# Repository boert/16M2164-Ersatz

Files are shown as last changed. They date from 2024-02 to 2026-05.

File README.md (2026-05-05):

# Ersatz für Hybridschaltkreis 16M2164

Der 16M2164 von KWH (Keramische Werke Hermsdorf) ist ein Speicherschaltkreis in Hybridbauweise.
Er ist vermutlich nur in sehr geringen Stückzahlen hergestellt worden.
Der Hybridschaltkreis enthält 16 mal das Die (ein Stück vom Halbleiterwafer) des Schaltkreises U2164 sowie einige Stützkondensatoren auf einem Keramiksubstrat.  
Der U2164 ist ein dynamischer RAM mit 64kBit.
In Summe enthält der 16M2164 ein MegaBit bzw. 128 kByte Speicher.

Zum Einsatz kommt der Schaltkreis 16M2164 im Speichermodul M036 für den KC85 aus Mühlhausen [^1].  
Um die unbestückten Leiterplatte, die für dieses Modul im Umlauf sind, nutzen zu können, benötigt man i.d.R. einen Ersatz für den 16M2164.

Von U. Zander stammt die urspüngliche Idee einer Schaltkreisersatzplatine, die nur mit vier dRAM-Schaltkreisen auskommt [^2].
Diese Lösung funktioniert leider nicht perfekt.

> [!Note]
> ### dynamischer Speicher
> Bei dynamischen Speichern wird die Information als Ladung in Kondensatoren abgebildet. Durch Leckströme verliert sich diese Ladung mit der Zeit und muß daher regelmäßig aufgefrischt werden (Refresh). Dies geschiet u.a. beim Aktivieren des /RAS-Signals. Der Hersteller gibt dabei an, in welchem Zeitraum jede ROW-Adresse einmal aktiviert werden muß. Normalerweise wird die angelegte ROW-Adresse vom Speichercontroller entsprechend hochgezählt. Bei einem geschickt adressierten Bildwiederholspeicher könnte man auf den Refresh verzichten, da dort durch regelmäßige Lesezugriffe die Information beim Lesen aufgefrischt wird.

In der folgenden Tabelle sind die Refreshzyklen eingier dRAM-Hersteller aufgeführt:

Hersteller  | Speicher-IC | Speichergröße | Refreshzyklen | Refreshzeit | Gehäuse
----------  | ----------- | ------------: | ------------: | ----------: | -------
&nbsp;      | &nbsp;      | _x1 Bit dRAMs_ 
Mostek      | MK4096      |   4k x 1      |   64          |  2 ms       | DIP16
Mostek      | MK4116      |  16k x 1      |  128          |  2 ms       | DIP16
NEC         | µPD4164     |  64k x 1      |  128          |  2 ms       | DIP16
Mostek      | MK4564      |  64k x 1      |  128          |  2 ms       | DIP16, PLCC18
Mostek      | MK4164      |  64k x 1      |  128          |  2 ms       | DIP16
National    | NMC4164     |  64k x 1      |  256          |  4 ms       | DIP16
Siemens     | HYB4164     |  64k x 1      |  256          |  4 ms       | DIP16
Mostek      | MK41256     | 256k x 1      |  256          |  4 ms       | DIP16, PLCC18
Siemens     | HYB51100    |   1M x 1      |  512          |  8 ms       | SOJ26
&nbsp;      | &nbsp;      | _x4 Bit dRAMs_ 
TI          | TMS4416     |  16k x 4      |  256          |  4 ms       | DIP18, PLCC18
TI          | SMJ4464     |  64k x 4      |  256          |  4 ms       | DIP18, PLCC18
NEC         | µPD41464    |  64k x 4      |  256          |  4 ms       | DIP18, PLCC18
TI          | SMJ4464     |  64k x 4      |  256          |  4 ms       | DIP18, PLCC18
Mitsubishi  | M5M4464A    |  64k x 4      |  256          |  4 ms       | DIP18, PLCC18, ZIP20
Samsung     | KM41464A    |  64k x 4      |  256          |  4 ms       | DIP18, PLCC18, ZIP20
Siemens     | HYB514256   | 256k x 4      |  512          |  8 ms       | DIP20, SOJ26/20
NEC         | µPD424400   |   1M x 4      | 1024          | 16 ms       | TSOP26, SOJ26/20

Eine Vergleichstabelle von 64k-Bit dRAM-Chips findet sich unter [^7].

Die verwendeten Speicher-IC der Größe 64k x 4 Bit benötigen alle 256 Refreshzyklen. Damit muß der Zähler für den Refresh mindestens acht Bit breit sein.
Die U880/Z80-CPU enthält nur einen 7 Bit-Refreshzähler, der für die Bausteine mit 64 oder 128 Refreshzyklen ausreichend ist.
Die obere Hälfte des Speichers erhält keinen definierten Refresh und verliert mit der Zeit ihren Inhalt.

Im Folgenden sind drei Wege aufgezeigt, um den fehlenden Speicher zu ersetzen: Variante R, Variante D und Variante S.

## Variante R: Refresh
Der übliche Weg ist es, den Refreshzähler zu erweitern.  
Ein Schaltung dafür findet sich z.B. in [^3].

Auch im Grundgerät D001 (KC85/4) werden aus den Signalen /rfsh, mreq und ab6 die Signale RF7 und RF8 gebildet, die den Refreshzähler des Z80 auf 9 Bit erweitern:

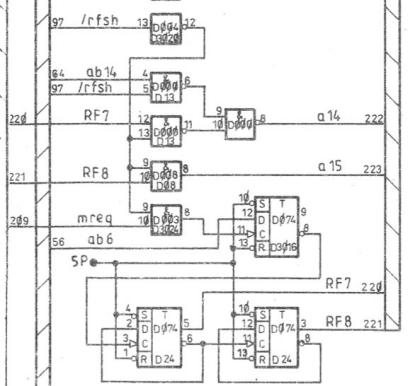
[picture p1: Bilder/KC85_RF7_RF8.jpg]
KC85/4, erweiterter Refresh
  

Der erweiterte Refreshzähler steht leider nur den interne RAM-Bausteinen auf der Hauptplatine zur Verfügung.

Am Modul 16M2164 steht weder der erweiterte Refreshzähler, noch das eigentliche Refresh-Signal zur Verfügung.  
Zumindest des Refresh-Signal müsste auf separatem Weg zugeführt werden.  
Daher wurde diese Lösung nicht weiter verfolgt.

## Variante D: dynamischer RAM
Im Robotrontechnik-Forum ist ein Bild vom Innenaufbau des 16M2164 verlinkt [^4]. Mit etwas Geschick lassen sich die 16 Stück U2164 auf einer Aufsteckplatine plazieren und so die Schaltung des 16M2164 1:1 nachbilden.
Die erste Hälfte der Schaltkreise sitzt direkt auf der Adapterplatine. Die zweite Hälfte wird huckepack auf die bereits eingelöteten Schaltkreise gelötet und bis auf das /CAS-Signal parallel geschaltet.
Die die untere Hälfte wird mit dem Signal /CAS0 aktiv. Die obere Hälfte wird entsprechend mit dem /CAS1-Signal aktiv.

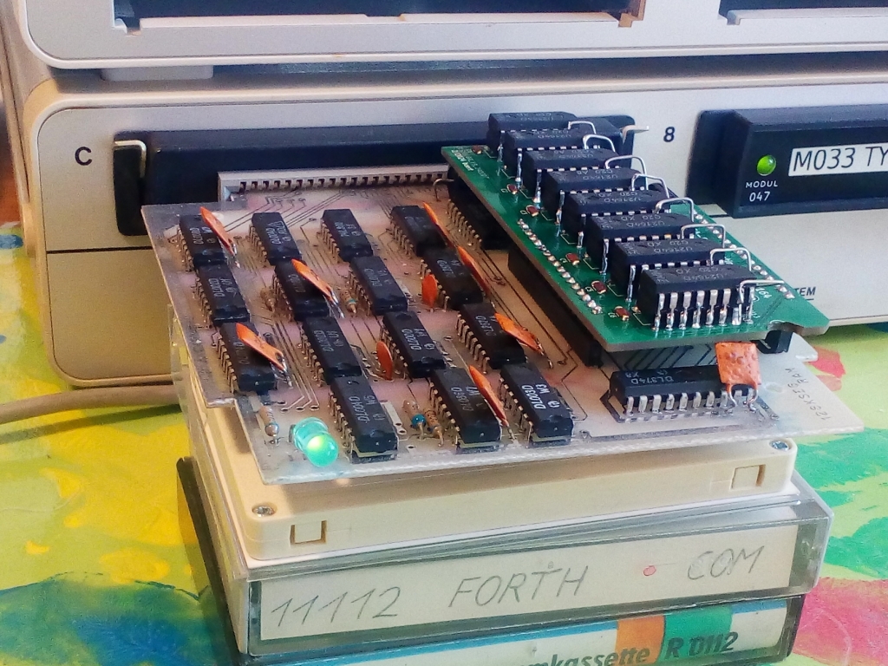
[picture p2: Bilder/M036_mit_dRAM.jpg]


Der große Nachteil dieser Lösung: sie benötigt zuviel Platz und passt nicht mehr in ein Modulgehäuse bzw. den Modulschacht.
Das M036 läßt sich so nur offen an einem Adapter M007 betreiben.

## Variante S: statischer RAM
Warum ersetzen wir nicht die dRAM-Schaltkreise durch einen einzelnen SRAM der Größe 128kx8 Bit?
Ein SRAM benötigt die Signale /CS, /WE und /OE sowie Daten und Adressen.
Am Bestückungsplatz für das 16M2164 stehen die Signale /RAS, /CAS0 (unter Hälfte), /CAS1 (obere Hälfte) und /WE zur Verfügung. Die Adressenleitungen sind multiplext.

Die Adressen müssen wieder demultiplext werden und für die Steuersignale ist eine Signalanpassung nötig.
Ein Latch, was mit dem invertierten /RAS-Signal angesteuert wird, speichert die eine Hälfte der Adressinformation. Die andere Hälfte der Adresse wird direkt an den SRAM durchgereicht. Aus /CAS0 und /CAS1 wird das /CS-Signal gebildet. Aus dem Signal /WE wird noch das Signal /OE abgeleitet.

Da es ein RAM ist, dürfen Datenleitungen problemlos miteinander vertauscht werden. Ebenso kann man Adressleitungen tauschen, solange keine Sonderfunktionen realisiert sind.
Damit wird das Routing auf der zweilagigen Platine erleichtert.

Im Bild ist die Lösung zu sehen, die von der Grundfläche dem Original 16M2164 entspricht.
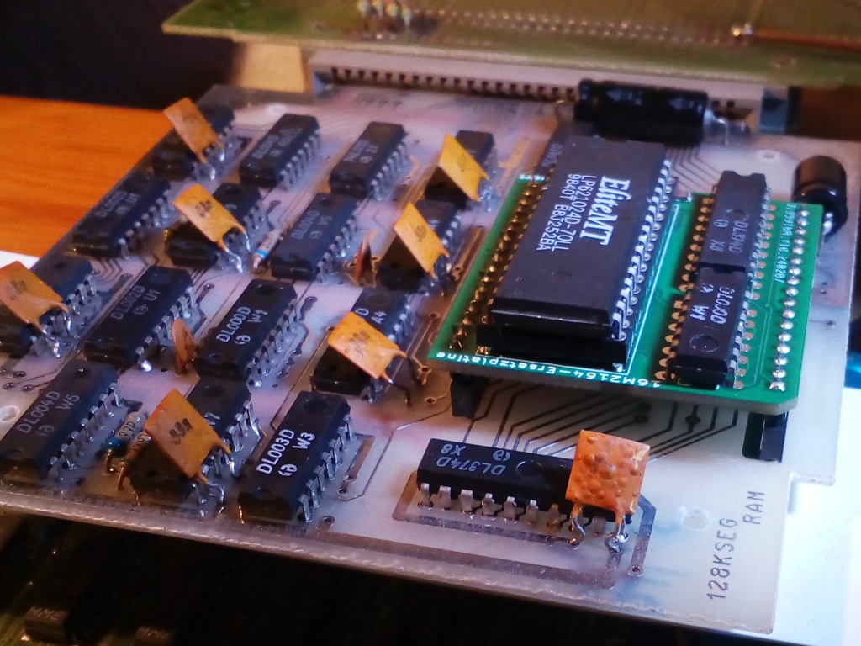
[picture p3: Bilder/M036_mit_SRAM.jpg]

Mit flachen Präzisions-Stiftleisten (und ohne IC-Sockel für den SRAM-Chip) läßt sich die Ersatzplatine im Modulgehäuse unterbringen.
Der IC-Sockel im Bild diente für den Test verschiedener SRAM-Schaltkreise.

# Test im M036 #
Für einen Speichertest im KC85/4 bzw. KC85/5 bietet sich das Programm RAMTEST3 an.
Um gezielt nur das Speichermodul M036 zu testen kann man mit `TESTM` den Modulschacht mit angeben, z.B. `TESTM 0C`.
Anschließend werden die acht Segmente des M036 durchgetestet:

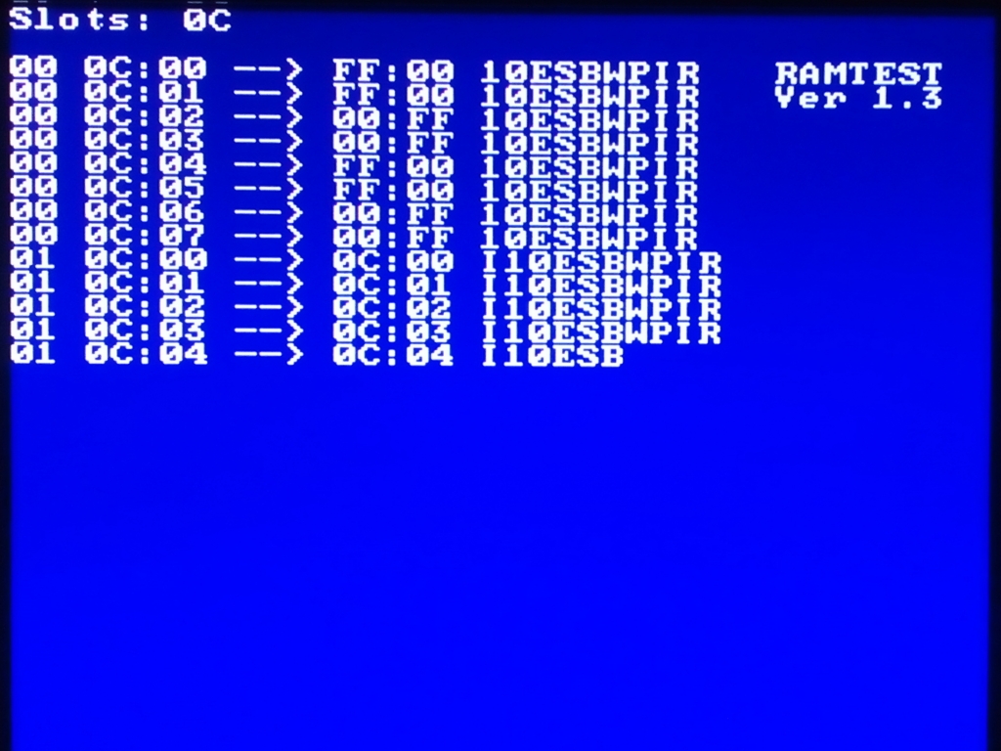
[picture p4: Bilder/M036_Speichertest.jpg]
M036 Speichertest


# Nutzung des Modul M036 #
## Typestar + RAMDOS ##

Das Textverarbeitungssystemm Typestar[^5] bringt das RAMDOS-System mit. Damit wird das KC-CAOS um eine RAM-Disk erweitert.
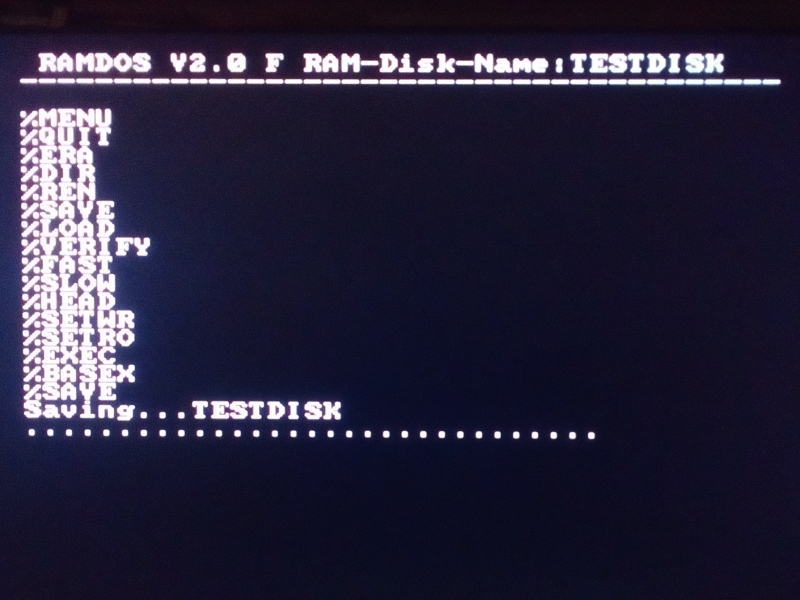
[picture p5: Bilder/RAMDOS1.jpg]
RAMDOS

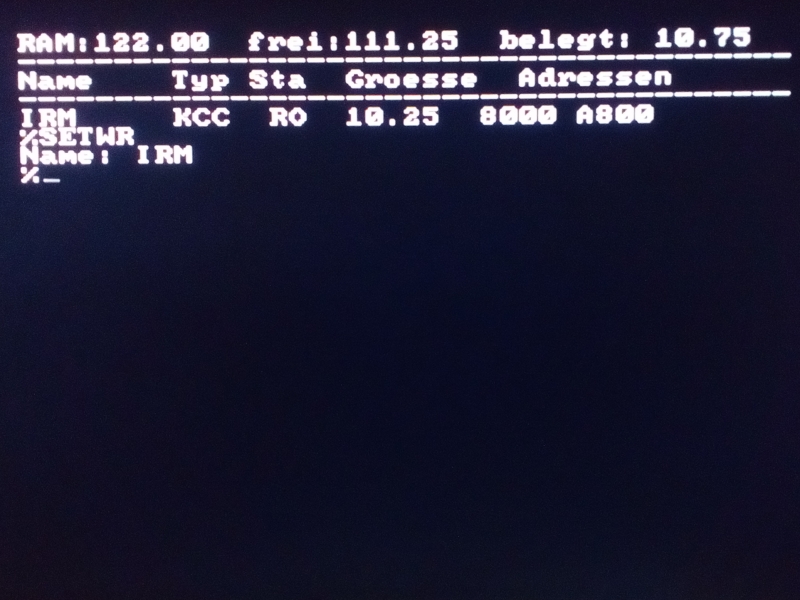
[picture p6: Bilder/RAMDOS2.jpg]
RAMDOS


## RAM-Disk für MicroDOS (D004) ##

Beim Start von MicroDOS [^6] werden vorhande RAM-Module als RAM-Disk (Laufwerk A:) initialisiert.
Das funktioniert auch mit dem Modul M036:

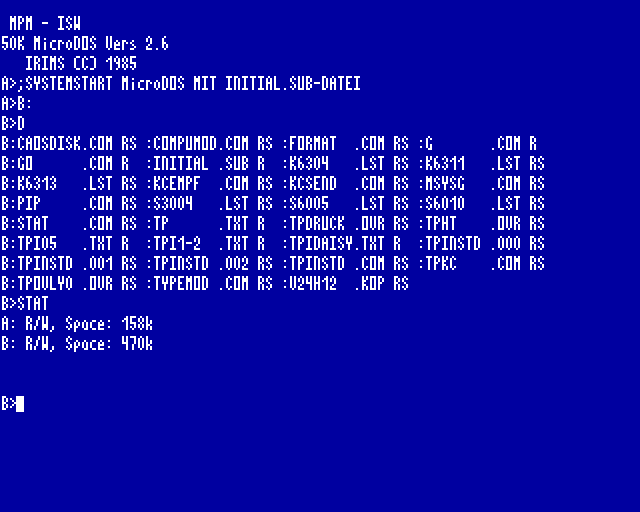
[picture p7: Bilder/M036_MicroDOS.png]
M036 als RAM-Disk


### Referenzen und Links
[^1]: Modul M036, Beschreibung, Bilder und Handbuch: [Modulbeschreibung auf mpm-kc85.de](http://www.mpm-kc85.de/html/m036_segram128k.htm)

[^2]: Schaltkreisersatzplatine 16M2164 [https://www.sax.de/~zander/ --> Hobby --> KC85 --> Hardware --> 128K-Segmented-RAM-Modul (M036)](https://www.sax.de/~zander/)

[^3]: c't 1984, Heft 9, M. Hungershausen, 8-Bit-Refresh für Z80

[^4]: Bild vom Innenleben des 16M2164 [Forum robotrontechnik.de](https://www.robotrontechnik.de/html/forum/thwb/showtopic.php?threadid=2115)

[^5]: Modul M033, Typestar: [Modulbeschreibung auf mpm-kc85.de](http://www.mpm-kc85.de/html/m033_typestar.htm)

[^6]: MicroDOS:  [Beschreibung auf mpm-kc85.de](http://www.mpm-kc85.de/html/MicroDOS.htm)

[^7]: Vergleichstabelle 64 kBit dRAM-Chips: [Examples of 4164 class RAM chips](https://www.minuszerodegrees.net/memory/4164.htm)

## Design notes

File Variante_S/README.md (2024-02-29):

## Variante S: statischer RAM

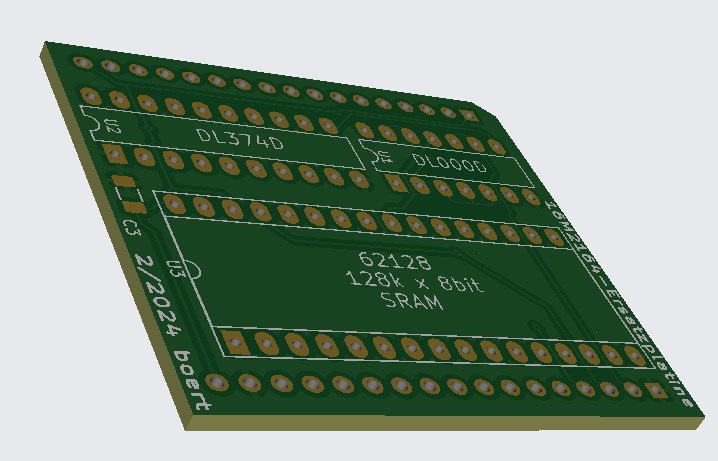
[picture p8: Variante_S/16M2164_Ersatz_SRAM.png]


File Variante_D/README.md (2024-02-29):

## Variante D: dynamischer RAM

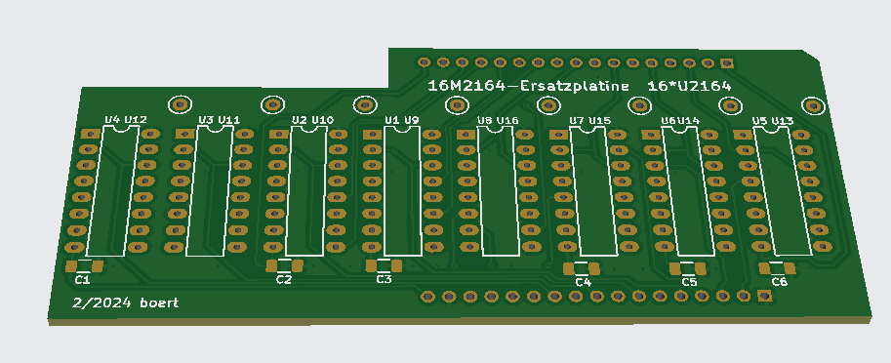
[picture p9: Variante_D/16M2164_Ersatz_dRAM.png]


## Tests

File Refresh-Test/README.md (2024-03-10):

# Refreshtest

Mit dem Refreshtest lässt sich die Zeit ermitteln, bis ein dynamischer RAM-Speicher seinen Inhalt vergisst.
Genutzt wird das Speichermodul M036 im KC85/4, speziell mit dem Ersatzschaltkreis 16M2164 nach [^1].

Dort wird versehentlich ein Teil des Speichers nicht aufgefrischt, was sich dieser Test zu nutze macht.

## Parameter

Die Voreinstellungen sind:  
Speichermodul M036 im Modulschacht '0C'  
Speichersegment 7, Steuerwort '1F'  

Ein anderer Modulschacht und ein anderes Modulsteuerwort können als Parameter mitgegeben werden.

## Programmablauf

Der zu testende RAM-Bereich liegt von 4000h bis 5FFFh.
Der interne RAM4 wird für den Test ausgeschaltet.

Der Speicherbereich wird mit einem Muster gefüllt und über dieses Muster wird eine einfache Prüfsumme gebildet (SUM16).
Die Prüfsumme dient als Referenz für den weiteren Programmlauf.
Anschließend wird Speicherinhalt zur Sichtkontrolle wird in den Bildspeicher kopiert.

Als Nächstes wird eine bestimmte Zeit gewartet, beginnend mit 20 ms.
Der Speicher wird wieder zur Anzeige gebracht und es wird die Prüfsumme gebildet.
Wenn die Prüfsumme stimmt, erfolgt die Ausschrift 'ok', es wird die Wartezeit erhöht und das Warten beginnt erneut.

Andernfalls erfolgt die Ausschrift 'FAIL'.
Nach Ablauf der längsten Wartezeit (1000 s) oder einem Tastendruck wird das Programm beendet.

## Beispiel

Im dargestellten Beispiel betrug die Raumtemperatur ca. 21° C.  
Nach 16 Sekunden sind alle Speicherstellen noch richtig:  
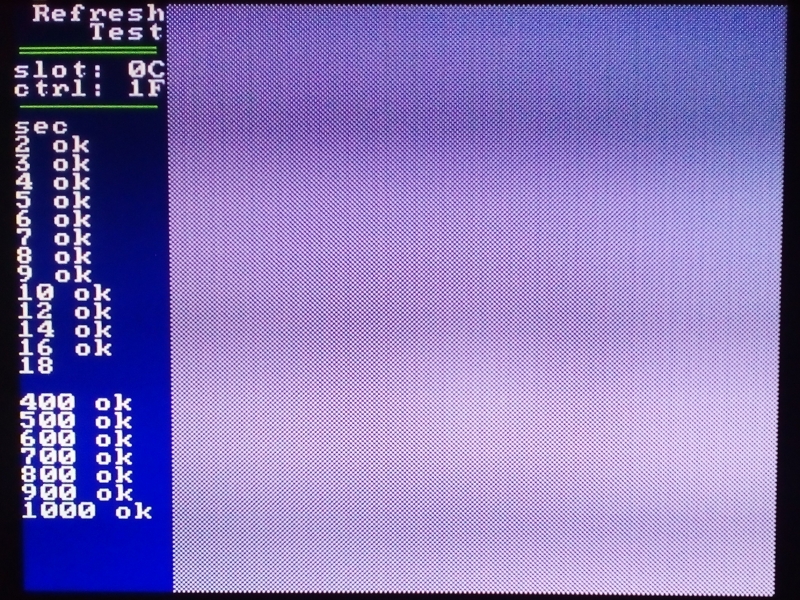
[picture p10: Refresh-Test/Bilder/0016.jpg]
Refreshtest nach 16 Sekunden


Nach ca. 30 Sekunden kippt die erste Speicherstelle:  
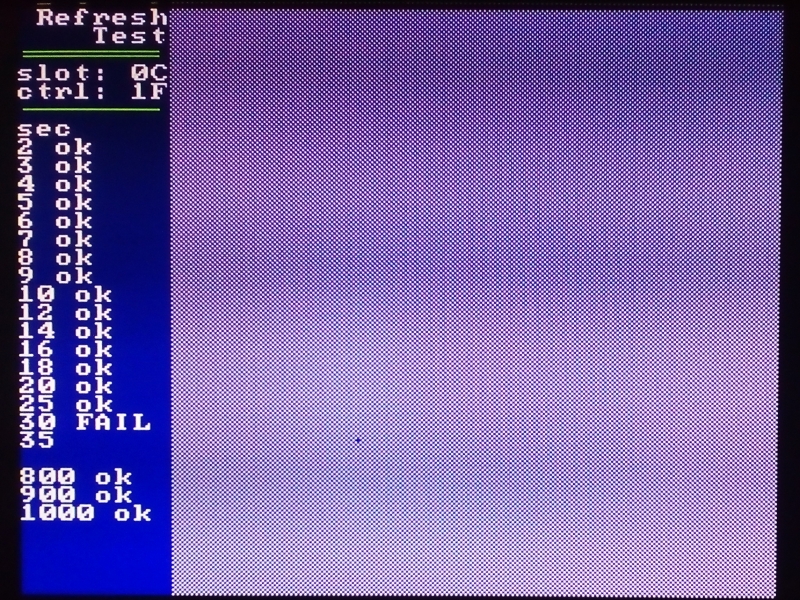
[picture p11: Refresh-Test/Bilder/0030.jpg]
Refreshtest nach 30 Sekunden


Nach ca. 60 Sekunden ohne Refresh lässt sich ein Muster erahnen:  
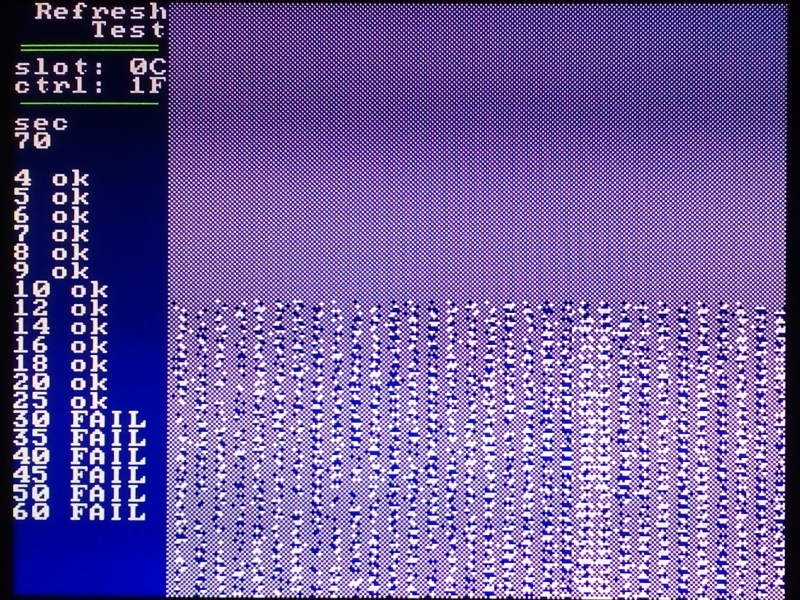
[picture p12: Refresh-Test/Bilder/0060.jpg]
Refreshtest nach 60 Sekunden


Die letzt Speicherstelle, die noch nicht gekippt ist, erkennt man nach ca. 180 Sekunden:  
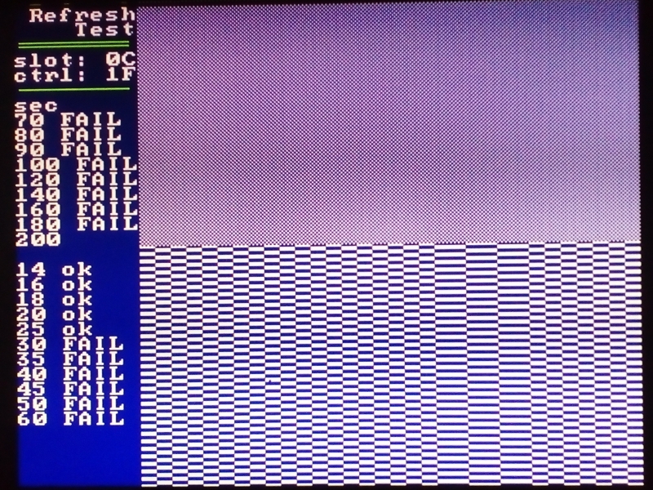
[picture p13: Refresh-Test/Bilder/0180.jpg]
Refreshtest nach 180 Sekunden


Nach ca. 200 Sekunden ohne Refresh sind alle Speicherstellen komplett im Ausgangszustand:  
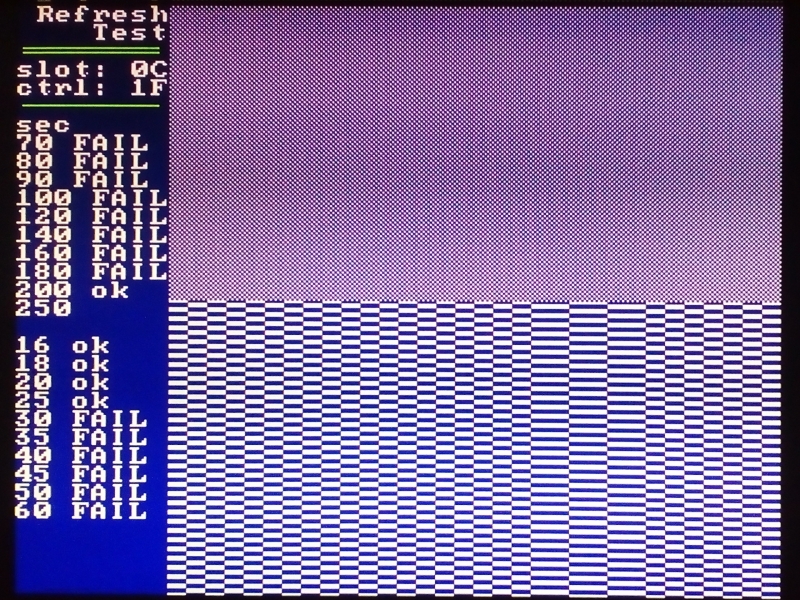
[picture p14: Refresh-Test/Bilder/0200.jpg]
Refreshtest nach 200 Sekunden
  
Die einfache Prüfsumme entspricht dann zufällig wieder dem zu Beginn gebildeten Referenzwert. 

### Referenzen und Links

[^1]: Schaltkreisersatzplatine 16M2164 [https://www.sax.de/~zander/ --> Hobby --> KC85 --> Hardware --> 128K-Segmented-RAM-Modul (M036)](https://www.sax.de/~zander/)

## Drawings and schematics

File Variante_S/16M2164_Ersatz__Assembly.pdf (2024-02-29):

A

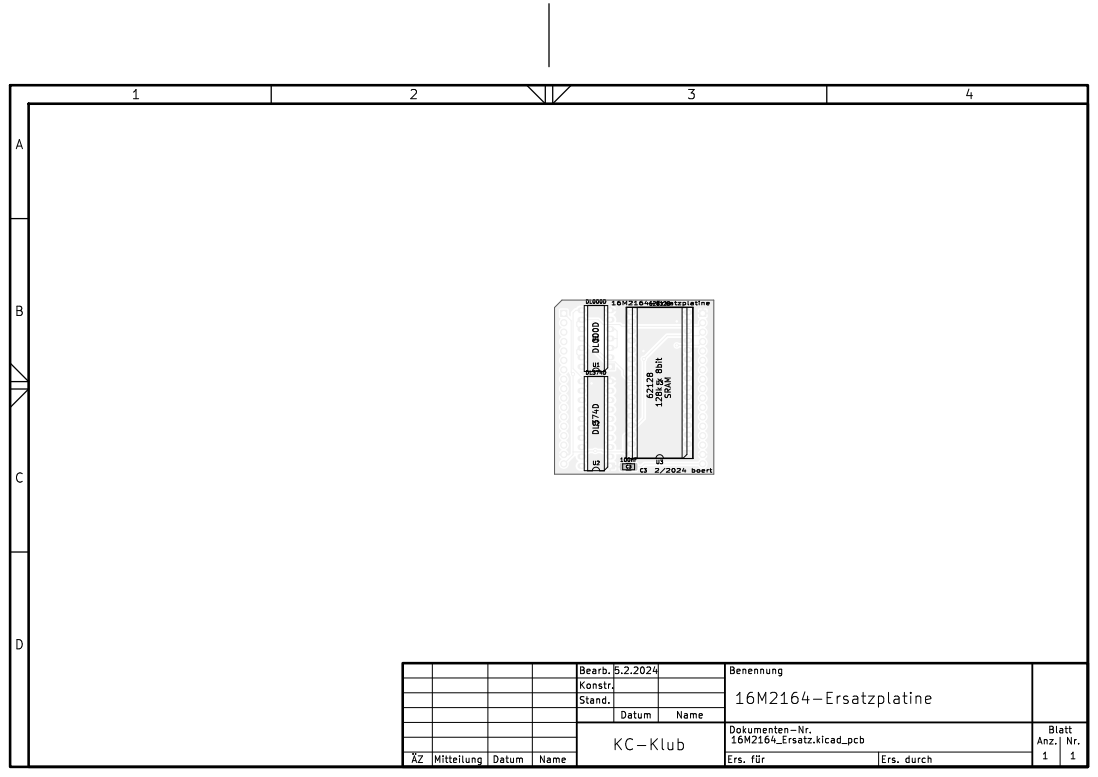
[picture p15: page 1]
boert; 16M2164-Ersatzplatine 62128 128k x 8bit SRAM DL374D DL000D; 16M2164_Ersatz.kicad_pcb; Stand.; Konstr.; Bearb.; Anz.; Blatt; Ers. für; Ers. durch; Dokumenten-Nr.; Benennung; Datum; Name; Mitteilung; 16M2164-Ersatzplatine; KC-Klub

A

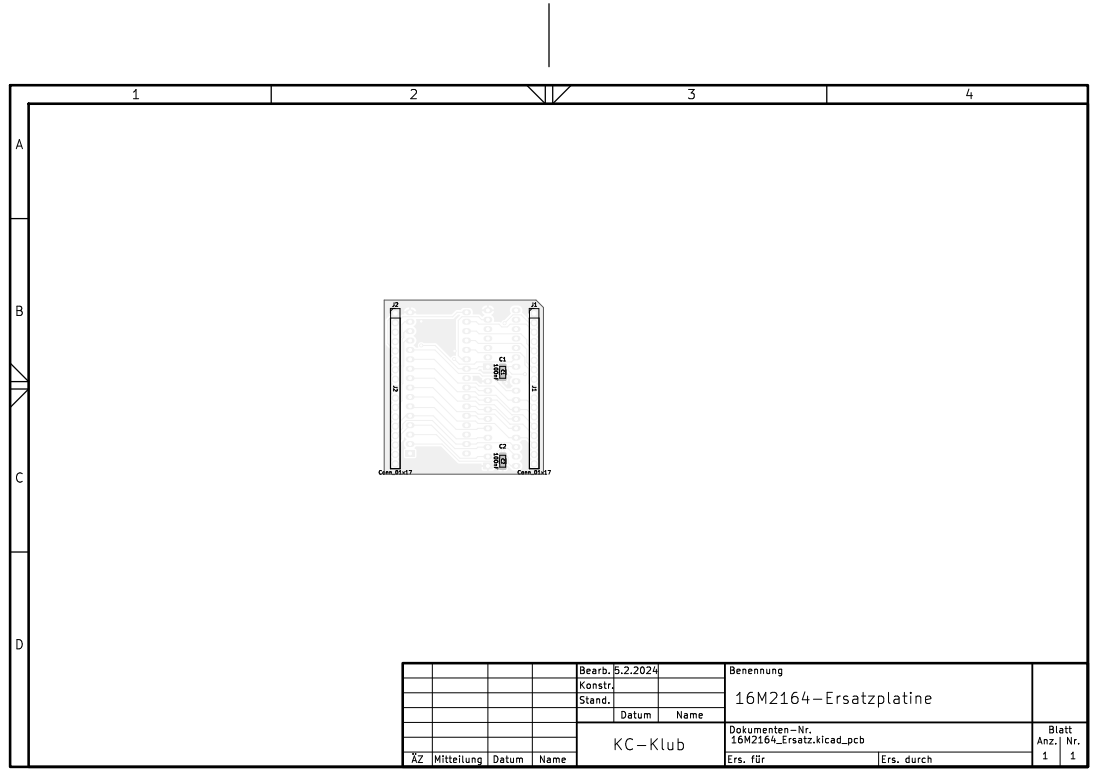
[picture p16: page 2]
Stand.; Konstr.; Bearb.; Benennung 16M2164-Ersatzplatine; Conn_01x17 J2; Conn_01x17 J1 100nF

A

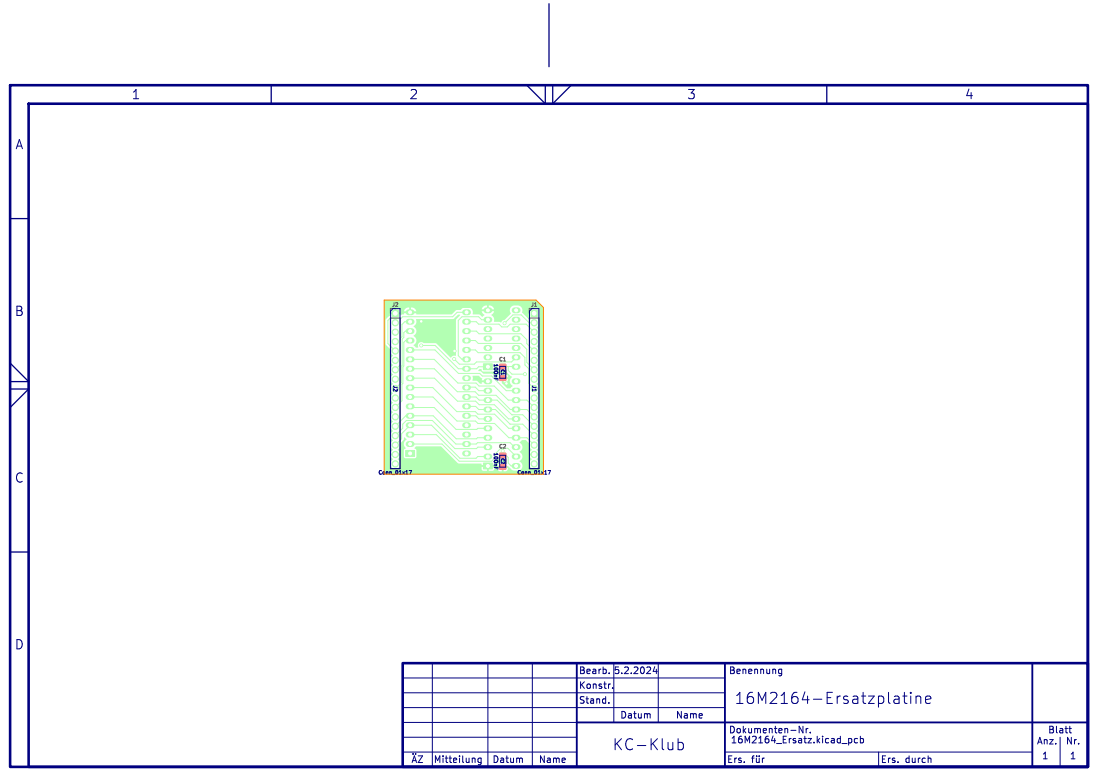
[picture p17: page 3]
Stand.; Konstr.; Bearb.; Benennung 16M2164-Ersatzplatine; Conn_01x17 J2; Conn_01x17 J1 100nF

A

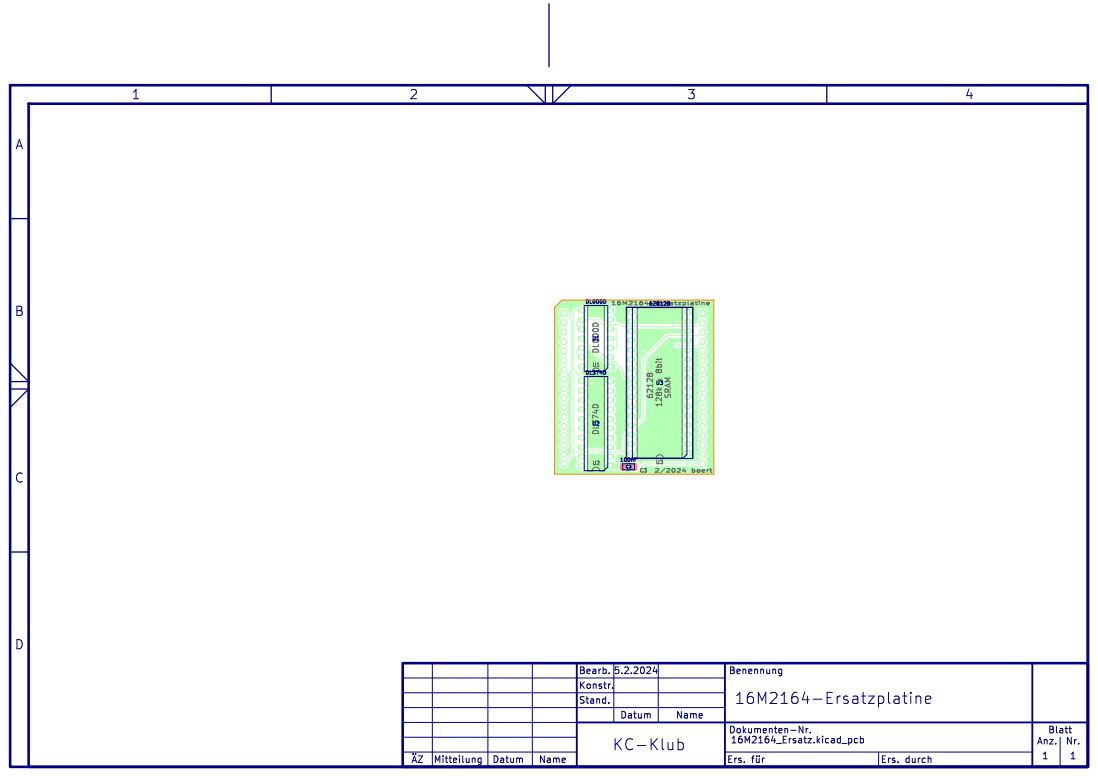
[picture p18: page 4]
boert; 16M2164-Ersatzplatine 62128 128k x 8bit SRAM DL374D DL000D; Stand.; Konstr.; Bearb.; Benennung 16M2164-Ersatzplatine

A

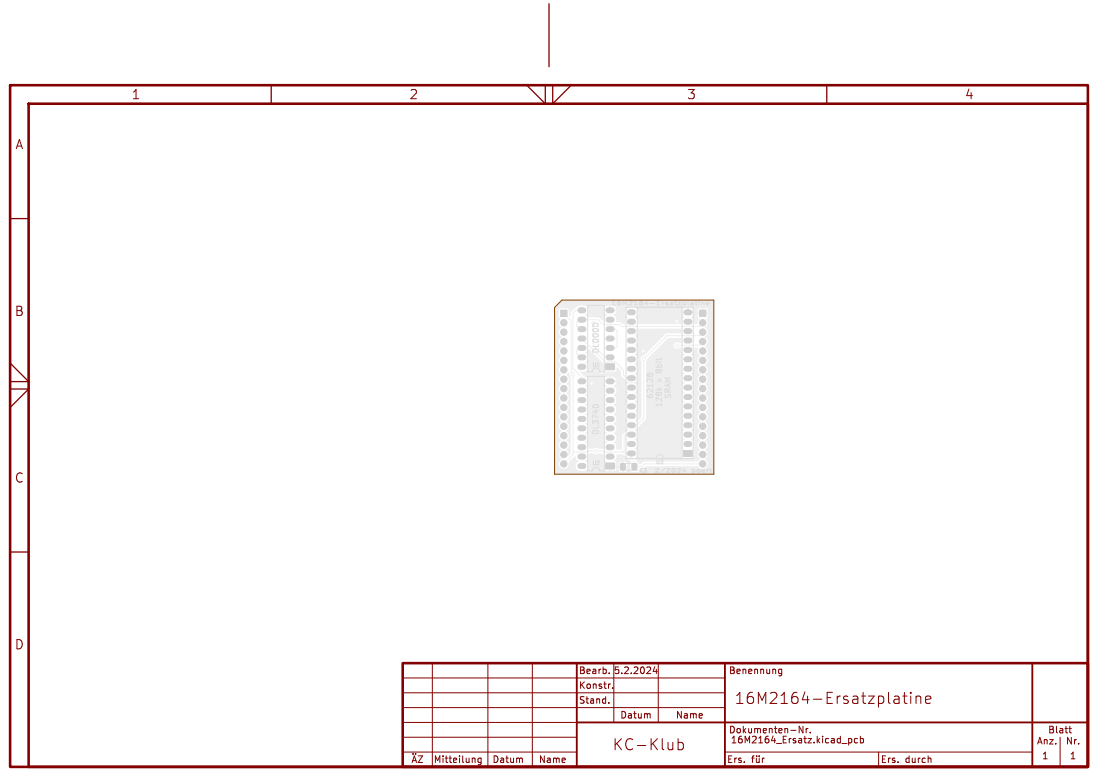
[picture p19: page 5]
boert; 16M2164-Ersatzplatine 62128 128k x 8bit SRAM DL374D DL000D; Stand.; Konstr.; Bearb.; Benennung 16M2164-Ersatzplatine

1 | 2 | 3 | 4

A

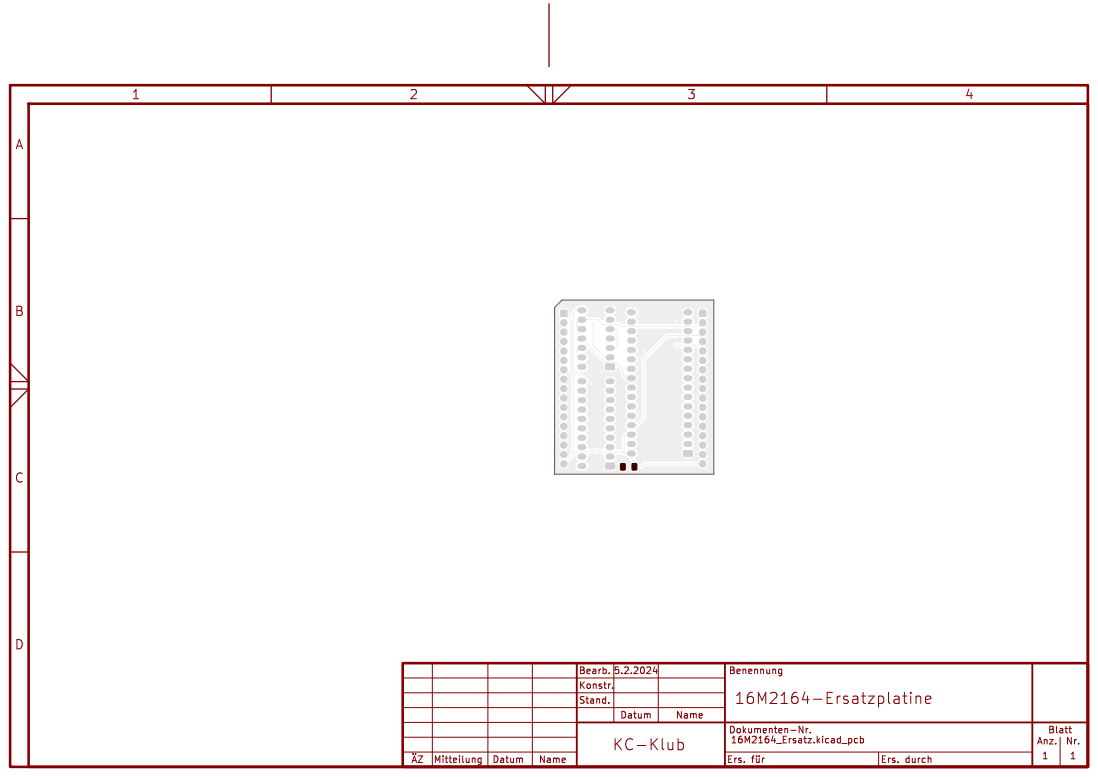
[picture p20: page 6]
Stand.; Konstr.; Bearb.; Benennung 16M2164-Ersatzplatine

A

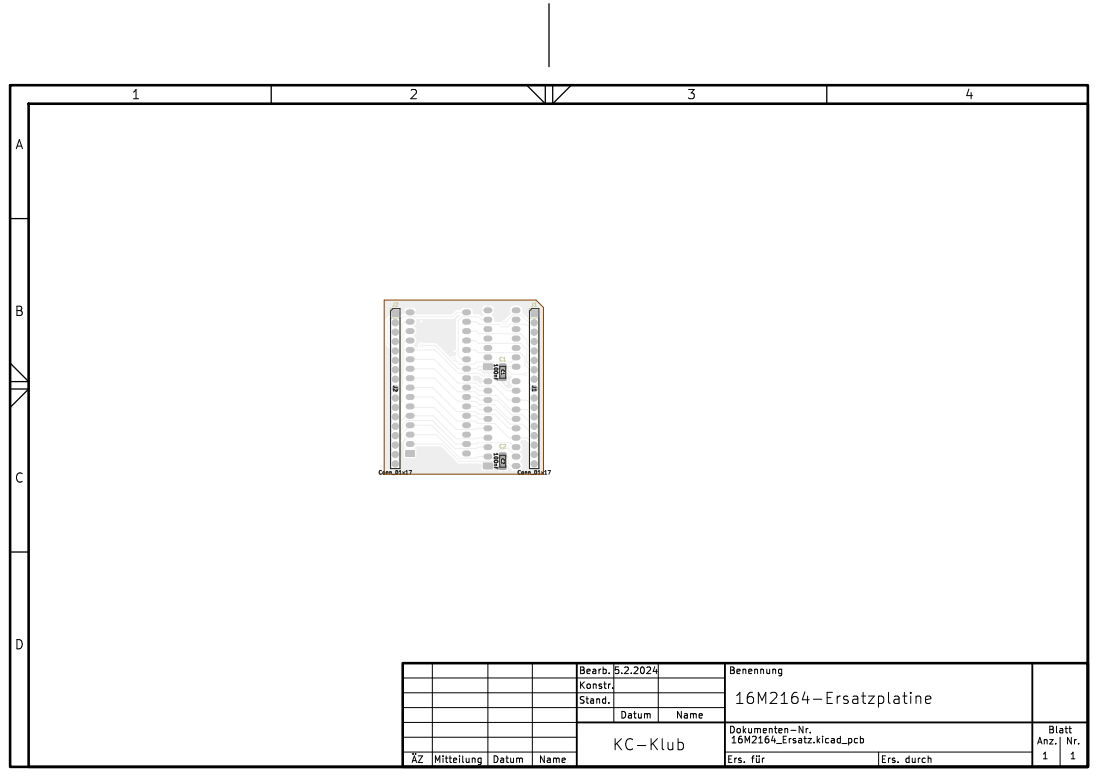
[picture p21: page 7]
J1 C2 C1 Conn_01x17 J2; Conn_01x17 J1 100nF; Stand.; Konstr.; Bearb.; Benennung 16M2164-Ersatzplatine

U1 1 | 2 | 3 | 4

A

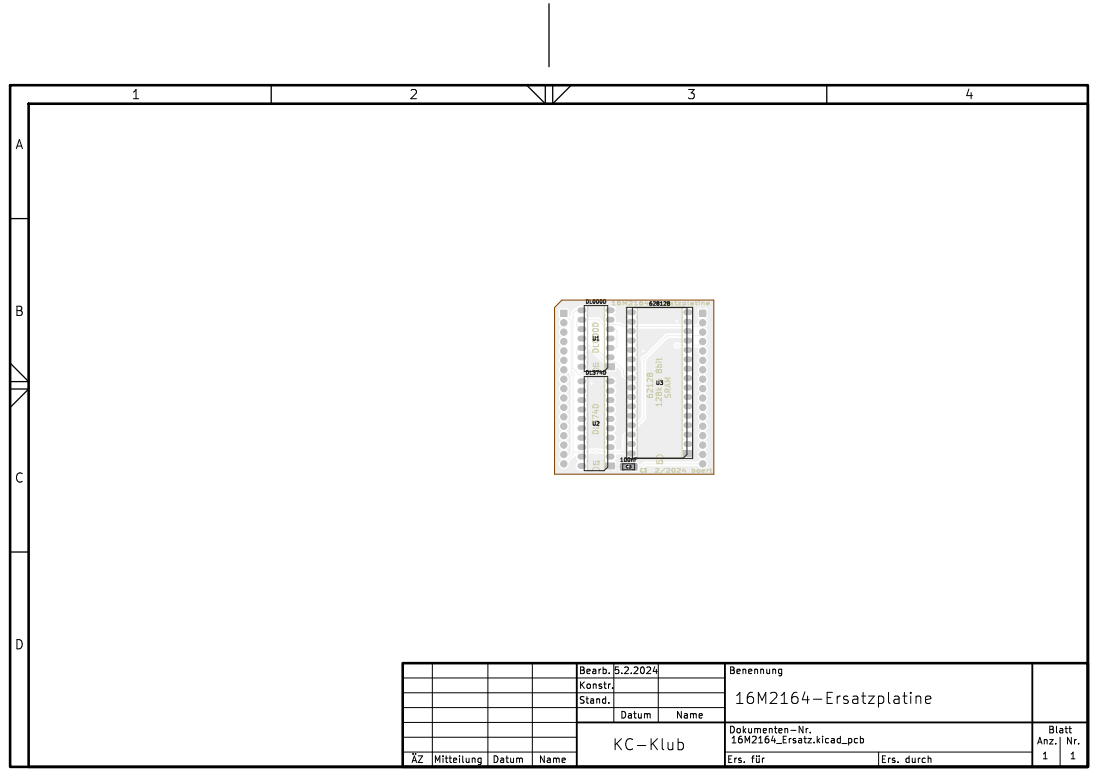
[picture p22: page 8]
boert; 16M2164-Ersatzplatine 62128 128k x 8bit SRAM DL374D DL000D; Stand.; Konstr.; Bearb.; Benennung 16M2164-Ersatzplatine

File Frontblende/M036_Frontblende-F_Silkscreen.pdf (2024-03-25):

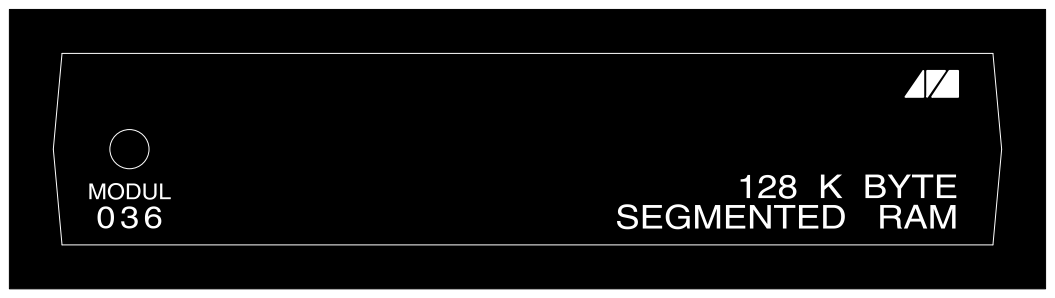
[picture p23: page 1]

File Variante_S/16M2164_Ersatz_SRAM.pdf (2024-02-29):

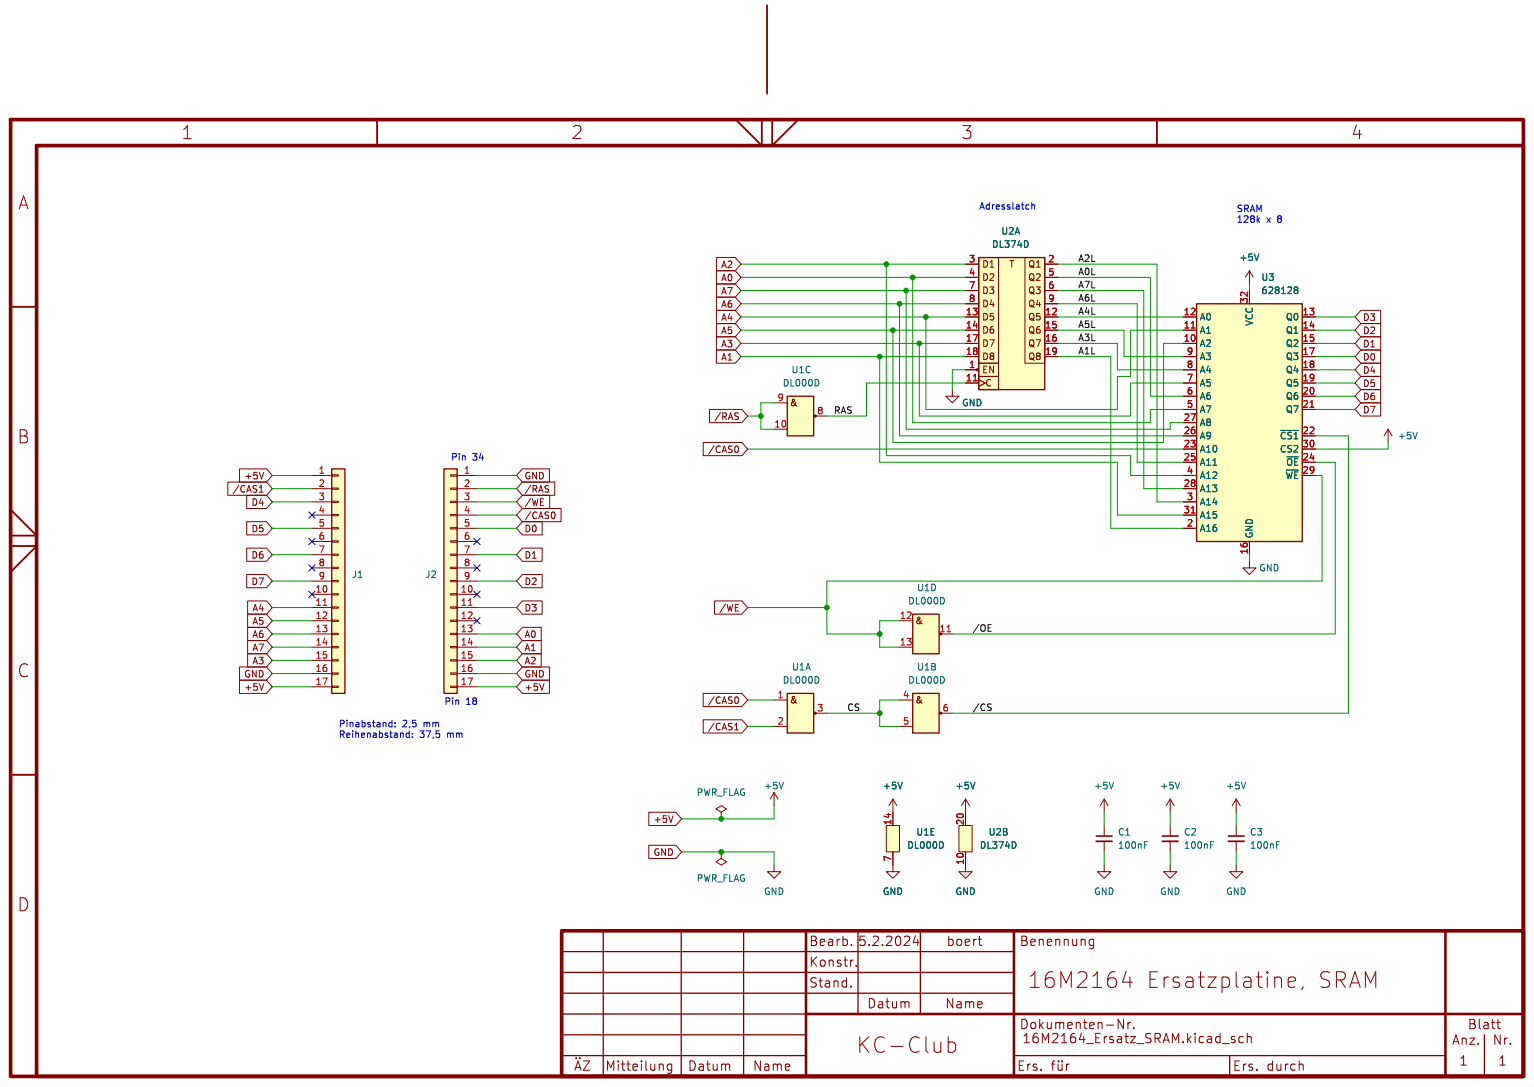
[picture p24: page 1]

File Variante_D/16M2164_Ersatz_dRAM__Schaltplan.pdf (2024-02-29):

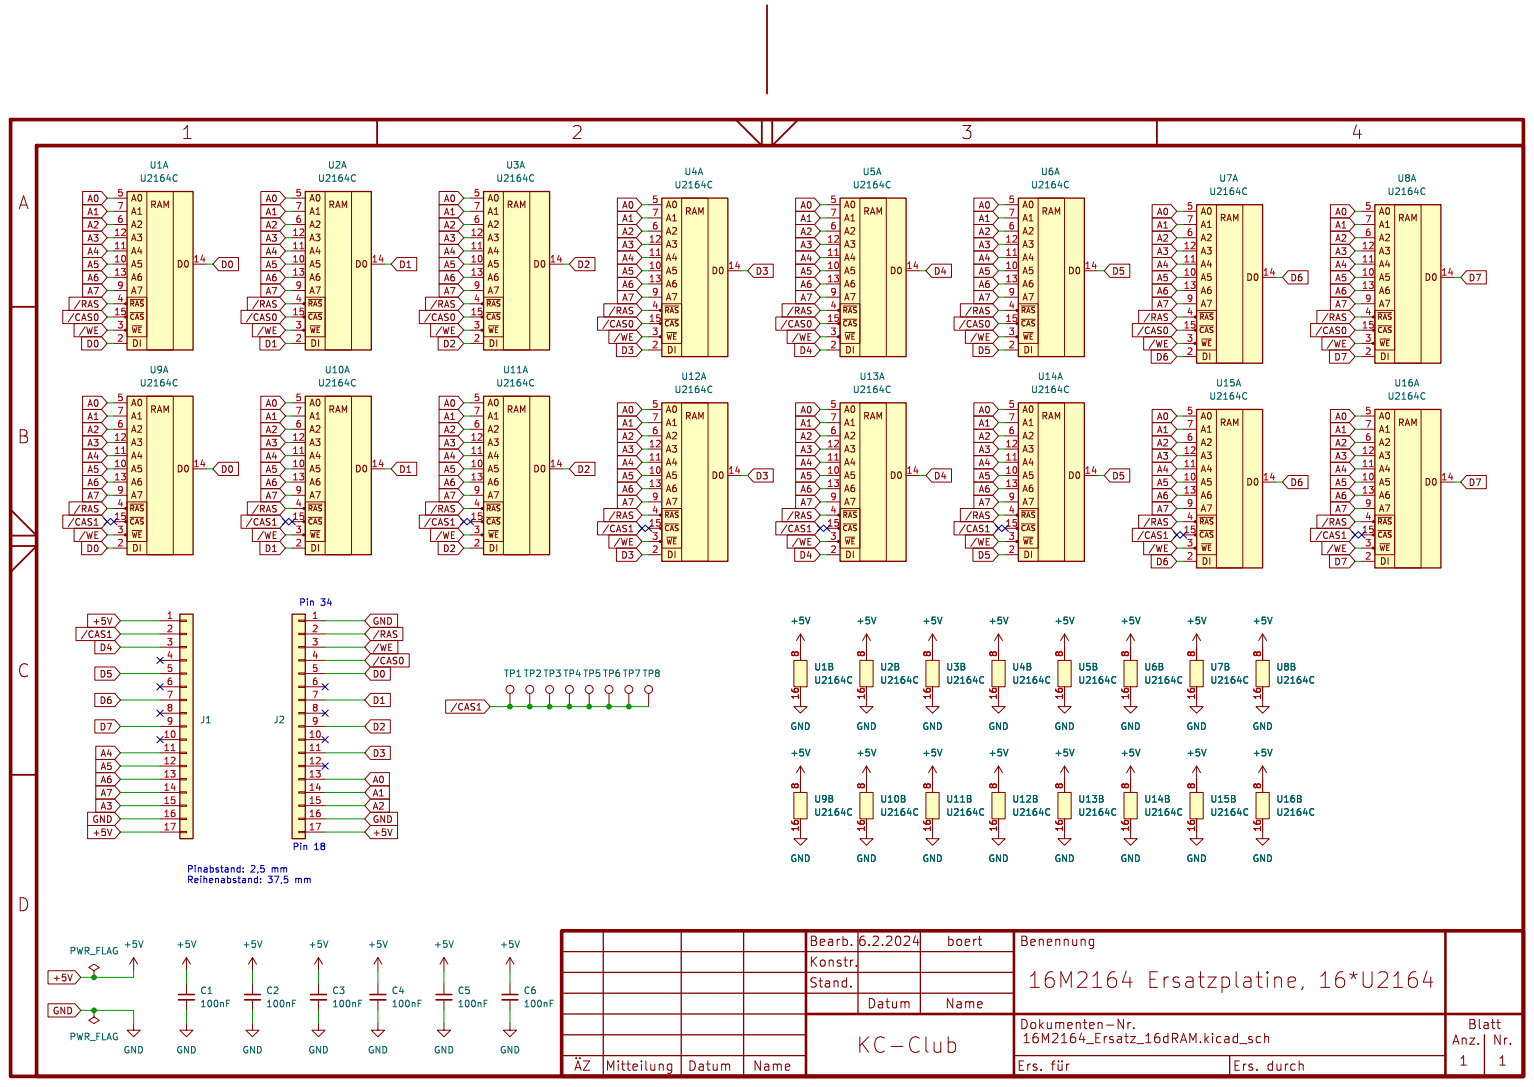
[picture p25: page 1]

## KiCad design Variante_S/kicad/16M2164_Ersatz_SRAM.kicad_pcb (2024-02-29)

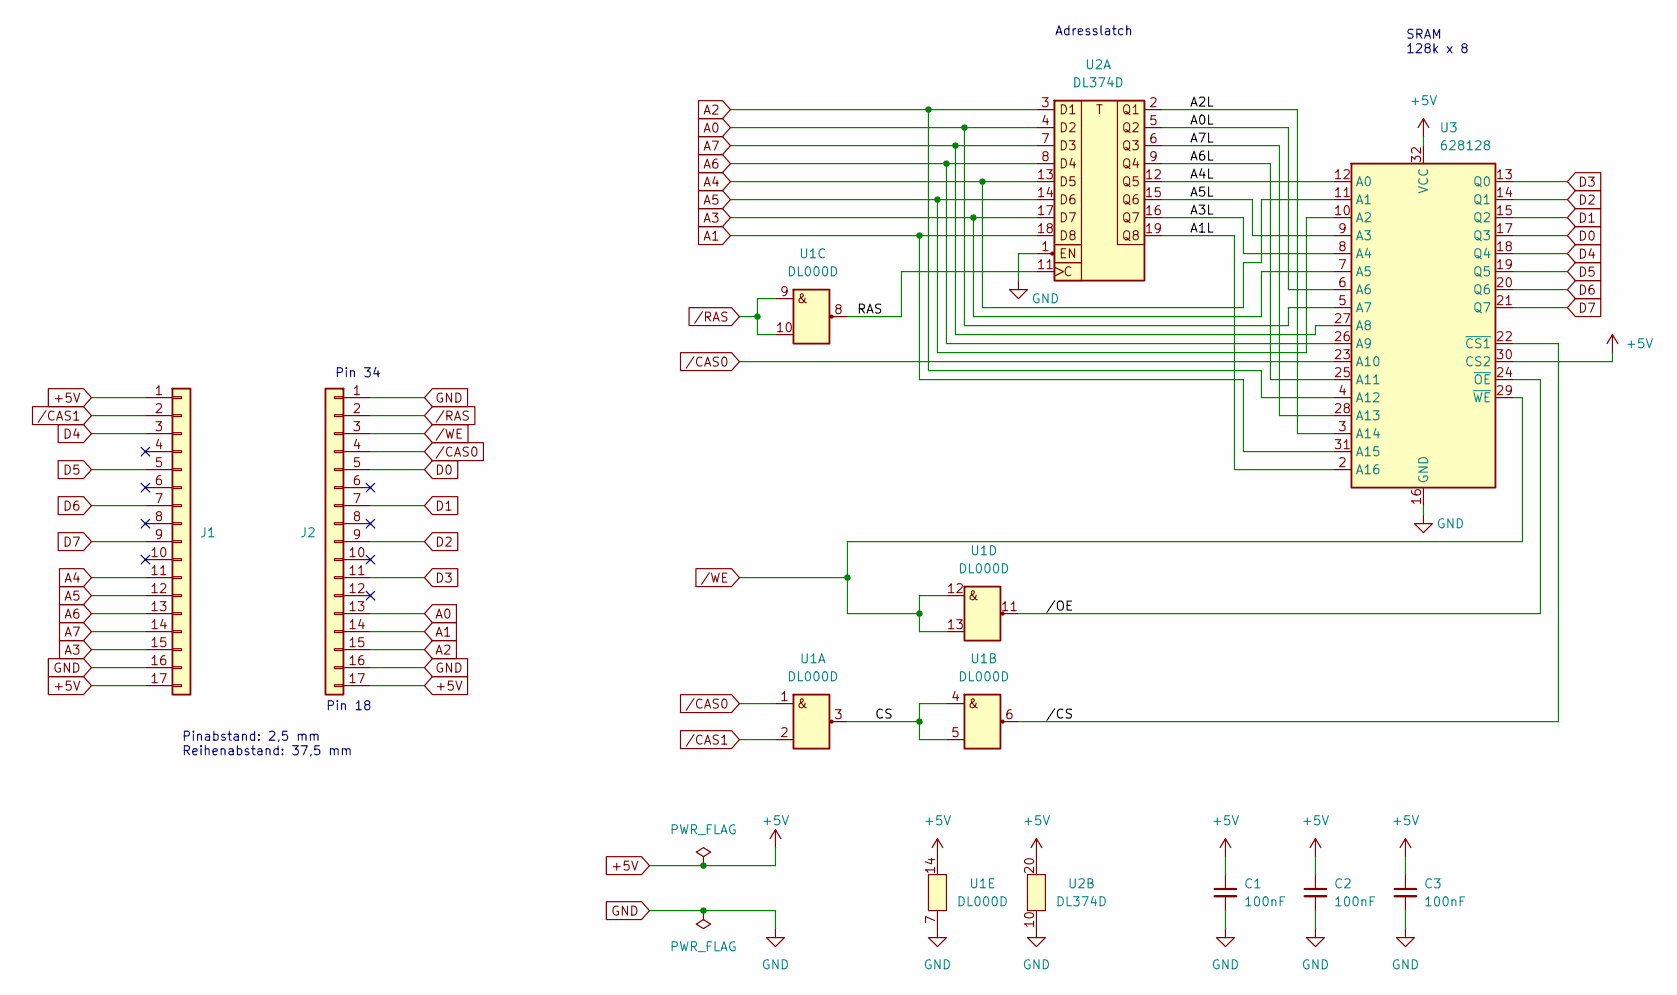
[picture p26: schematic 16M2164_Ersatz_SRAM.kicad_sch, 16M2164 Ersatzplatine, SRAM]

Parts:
C1, C2, C3: 100nF; C_1206_3216Metric_Pad1.33x1.80mm_HandSolder
J1, J2: Conn_01x17; PinHeader_1x17_P2.54mm_Vertical
U1: DL000D; DIP-14_W7.62mm_LongPads
U2: DL374D; DIP-20_W7.62mm_LongPads
U3: 628128; DIP-32_W15.24mm_Socket_LongPads

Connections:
+5V: C1.1, C2.1, C3.1, J1.1, J1.17, J2.17, U1.14 (Vcc), U2.20 (Vcc), U3.30 (CS2), U3.32 (VCC)
/A0L: U2.5 (Q2), U3.6 (A6)
/A1L: U2.19 (Q8), U3.2 (A16)
/A2L: U2.2 (Q1), U3.3 (A14)
/A3L: U2.16 (Q7), U3.8 (A4)
/A4L: U2.12 (Q5), U3.12 (A0)
/A5L: U2.15 (Q6), U3.9 (A3)
/A6L: U2.9 (Q4), U3.25 (A11)
/A7L: U2.6 (Q3), U3.28 (A13)
/CS: U1.3 (Y1), U1.4 (A2), U1.5 (B2)
/RAS: U1.8 (Y3), U2.11 (C)
//CS: U1.6 (Y2), U3.22 (~CS1)
//OE: U1.11 (Y4), U3.24 (~OE)
A0: J2.13, U2.4 (D2), U3.5 (A7)
A1: J2.14, U2.18 (D8), U3.31 (A15)
A2: J2.15, U2.3 (D1), U3.4 (A12)
A3: J1.15, U2.17 (D7), U3.7 (A5)
A4: J1.11, U2.13 (D5), U3.11 (A1)
A5: J1.12, U2.14 (D6), U3.10 (A2)
A6: J1.13, U2.8 (D4), U3.26 (A9)
A7: J1.14, U2.7 (D3), U3.27 (A8)
D0: J2.5, U3.17 (Q3)
D1: J2.7, U3.15 (Q2)
D2: J2.9, U3.14 (Q1)
D3: J2.11, U3.13 (Q0)
D4: J1.3, U3.18 (Q4)
D5: J1.5, U3.19 (Q5)
D6: J1.7, U3.20 (Q6)
D7: J1.9, U3.21 (Q7)
GND: C1.2, C2.2, C3.2, J1.16, J2.1, J2.16, U1.7 (GND), U2.1 (EN), U2.10 (GND), U3.16 (GND)
/CAS0: J2.4, U1.1 (A1), U3.23 (A10)
/CAS1: J1.2, U1.2 (B1)
/RAS: J2.2, U1.9 (A3), U1.10 (B3)
/WE: J2.3, U1.12 (A4), U1.13 (B4), U3.29 (~WE)

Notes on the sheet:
Adresslatch
Pin 34
SRAM 128k x 8
Pin 18
Pinabstand: 2,5 mm Reihenabstand: 37,5 mm

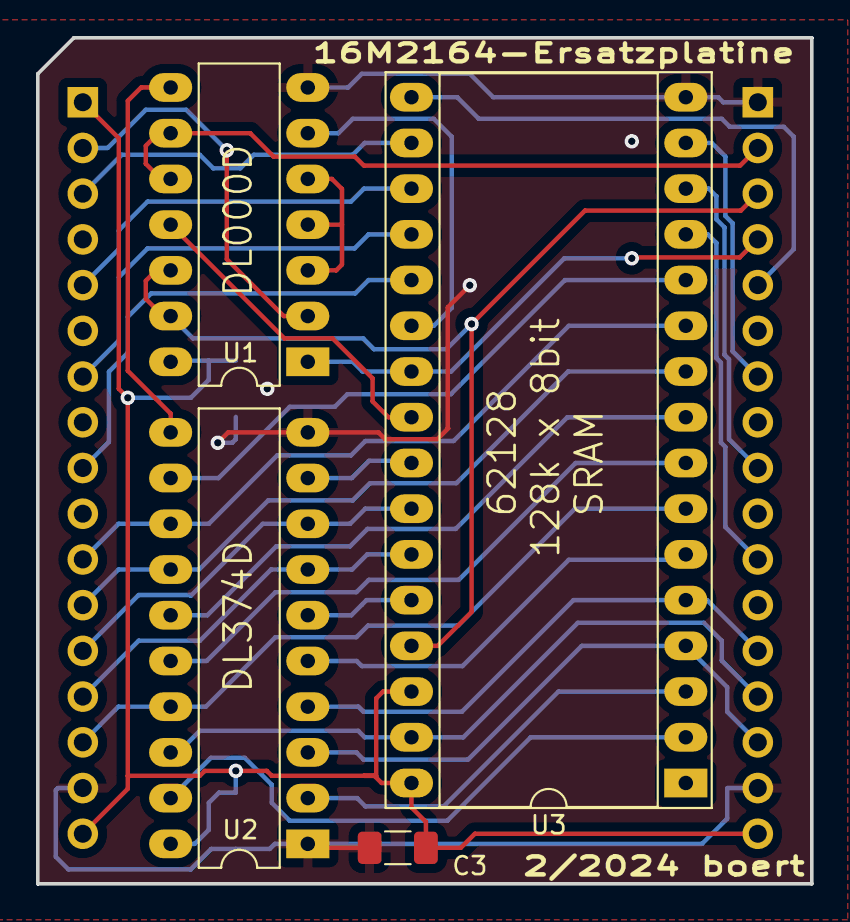
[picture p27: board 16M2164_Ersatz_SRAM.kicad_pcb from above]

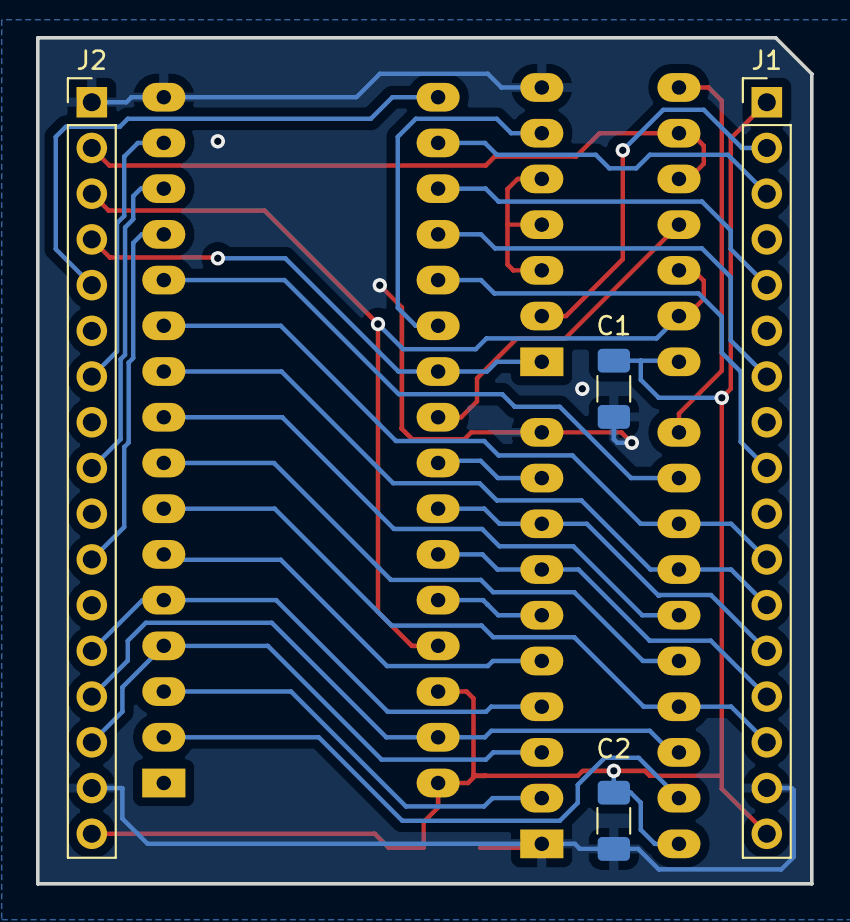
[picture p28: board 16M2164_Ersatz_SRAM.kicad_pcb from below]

Board: 2 copper layers, 43.0 x 47.0 mm, 8 parts (4 on the bottom side), 34 nets.

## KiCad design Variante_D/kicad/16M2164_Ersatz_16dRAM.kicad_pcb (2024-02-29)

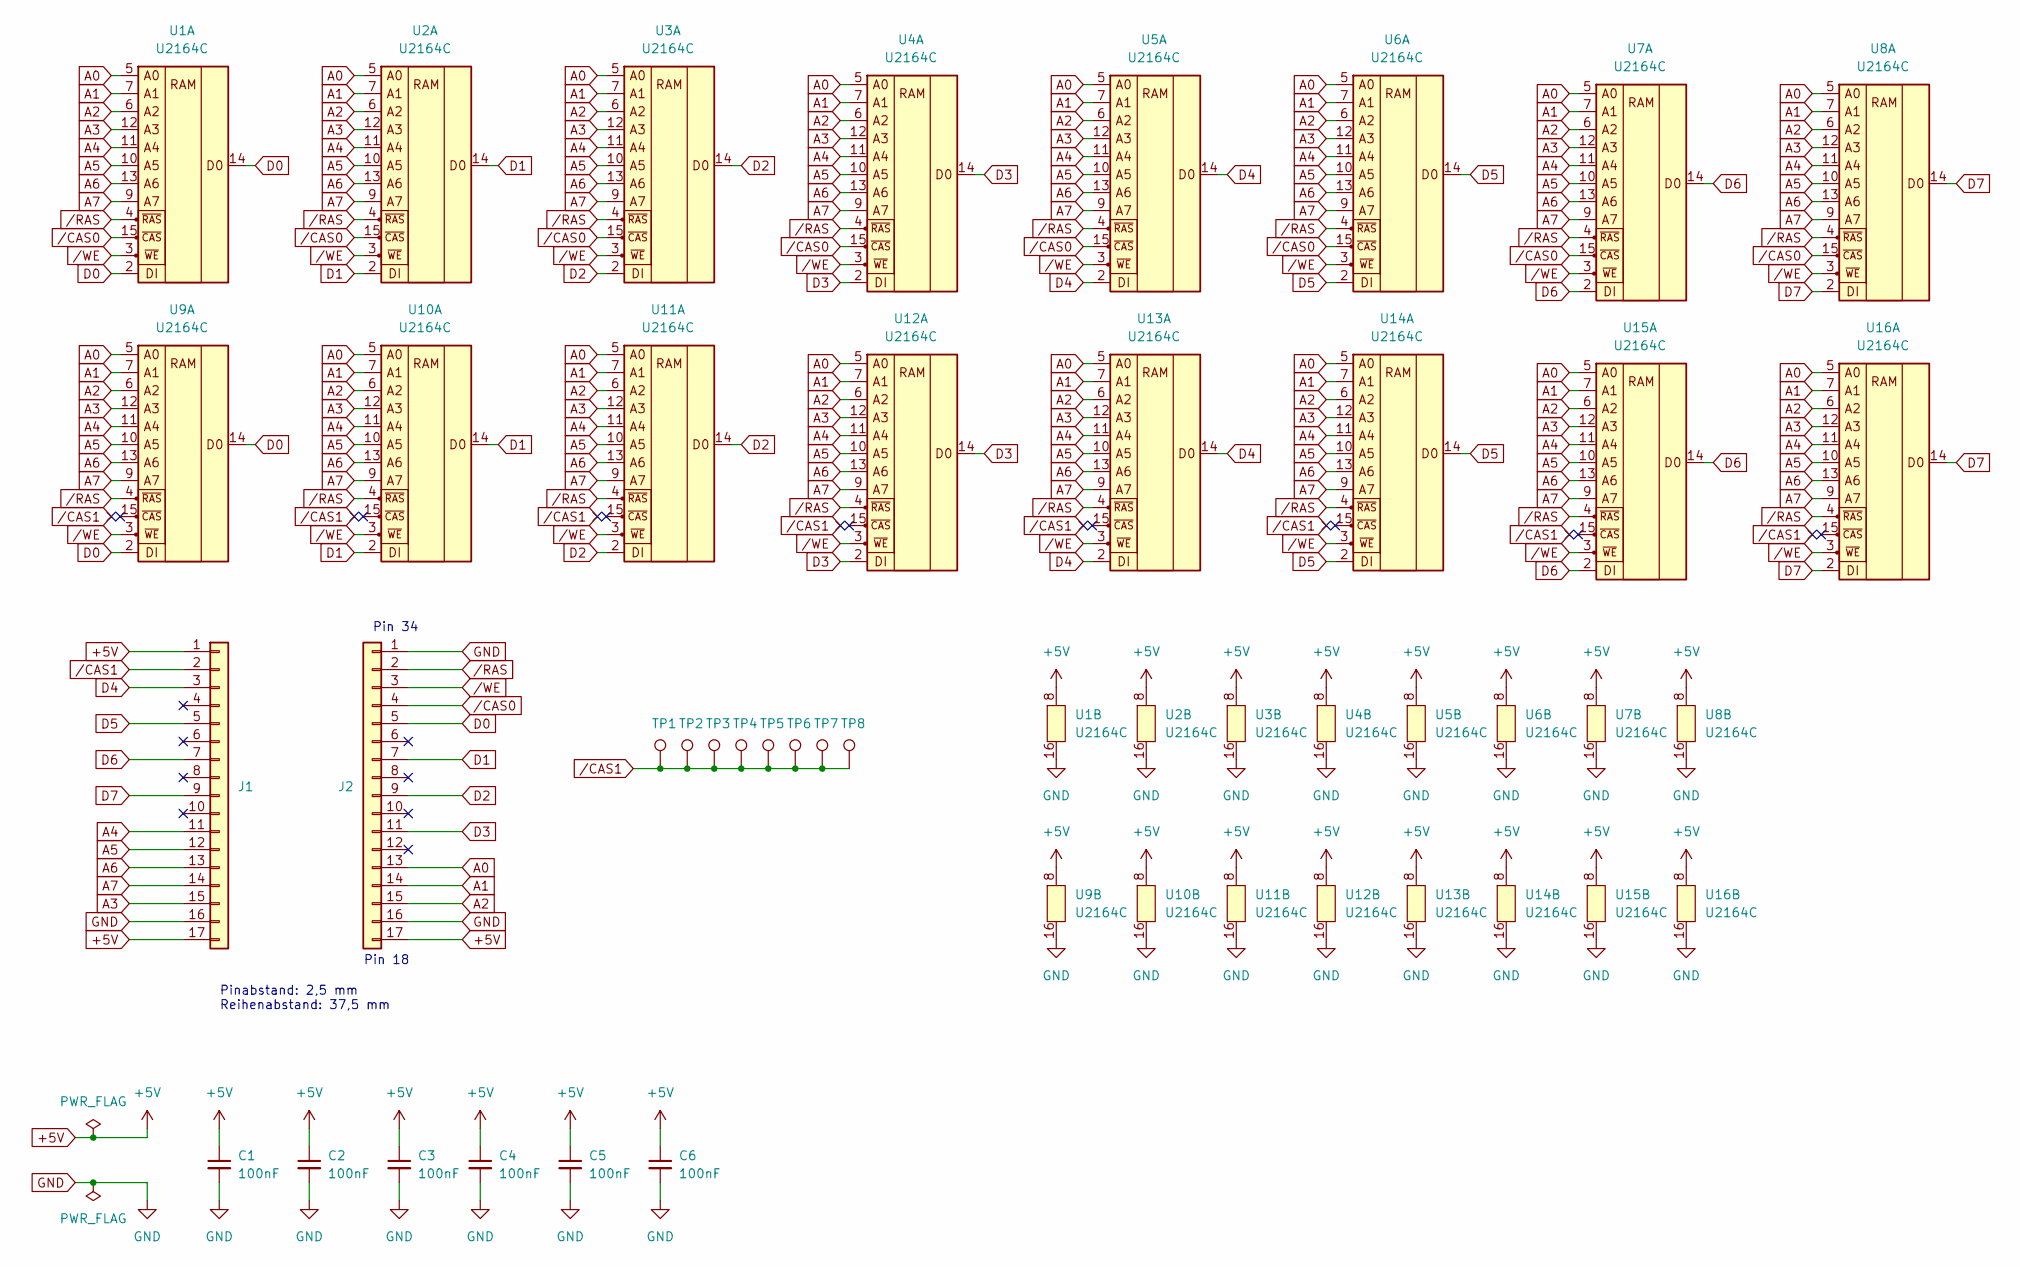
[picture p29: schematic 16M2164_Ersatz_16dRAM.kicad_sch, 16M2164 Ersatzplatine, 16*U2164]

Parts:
C1, C2, C3, C4, C5, C6: 100nF; C_1206_3216Metric_Pad1.33x1.80mm_HandSolder
J1, J2: Conn_01x17; PinHeader_1x17_P2.54mm_Vertical
TP1, TP2, TP3, TP4, TP5, TP6, TP7, TP8: TestPoint; TestPoint_Loop_D1.80mm_Drill1.0mm_Beaded
U1, U2, U3, U4, U5, U6, U7, U8, U9, U10, U11, U12, U13, U14, U15, U16: U2164C; DIP-16_W7.62mm_LongPads

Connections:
+5V: C1.1, C2.1, C3.1, C4.1, C5.1, C6.1, J1.1, J1.17, J2.17, U1.8 (Ucc), U2.8 (Ucc), U3.8 (Ucc), U4.8 (Ucc), U5.8 (Ucc), U6.8 (Ucc), U7.8 (Ucc), U8.8 (Ucc), U9.8 (Ucc), U10.8 (Ucc), U11.8 (Ucc), U12.8 (Ucc), U13.8 (Ucc), U14.8 (Ucc), U15.8 (Ucc), U16.8 (Ucc)
A0: J2.13, U1.5 (A0), U2.5 (A0), U3.5 (A0), U4.5 (A0), U5.5 (A0), U6.5 (A0), U7.5 (A0), U8.5 (A0), U9.5 (A0), U10.5 (A0), U11.5 (A0), U12.5 (A0), U13.5 (A0), U14.5 (A0), U15.5 (A0), U16.5 (A0)
A1: J2.14, U1.7 (A1), U2.7 (A1), U3.7 (A1), U4.7 (A1), U5.7 (A1), U6.7 (A1), U7.7 (A1), U8.7 (A1), U9.7 (A1), U10.7 (A1), U11.7 (A1), U12.7 (A1), U13.7 (A1), U14.7 (A1), U15.7 (A1), U16.7 (A1)
A2: J2.15, U1.6 (A2), U2.6 (A2), U3.6 (A2), U4.6 (A2), U5.6 (A2), U6.6 (A2), U7.6 (A2), U8.6 (A2), U9.6 (A2), U10.6 (A2), U11.6 (A2), U12.6 (A2), U13.6 (A2), U14.6 (A2), U15.6 (A2), U16.6 (A2)
A3: J1.15, U1.12 (A3), U2.12 (A3), U3.12 (A3), U4.12 (A3), U5.12 (A3), U6.12 (A3), U7.12 (A3), U8.12 (A3), U9.12 (A3), U10.12 (A3), U11.12 (A3), U12.12 (A3), U13.12 (A3), U14.12 (A3), U15.12 (A3), U16.12 (A3)
A4: J1.11, U1.11 (A4), U2.11 (A4), U3.11 (A4), U4.11 (A4), U5.11 (A4), U6.11 (A4), U7.11 (A4), U8.11 (A4), U9.11 (A4), U10.11 (A4), U11.11 (A4), U12.11 (A4), U13.11 (A4), U14.11 (A4), U15.11 (A4), U16.11 (A4)
A5: J1.12, U1.10 (A5), U2.10 (A5), U3.10 (A5), U4.10 (A5), U5.10 (A5), U6.10 (A5), U7.10 (A5), U8.10 (A5), U9.10 (A5), U10.10 (A5), U11.10 (A5), U12.10 (A5), U13.10 (A5), U14.10 (A5), U15.10 (A5), U16.10 (A5)
A6: J1.13, U1.13 (A6), U2.13 (A6), U3.13 (A6), U4.13 (A6), U5.13 (A6), U6.13 (A6), U7.13 (A6), U8.13 (A6), U9.13 (A6), U10.13 (A6), U11.13 (A6), U12.13 (A6), U13.13 (A6), U14.13 (A6), U15.13 (A6), U16.13 (A6)
A7: J1.14, U1.9 (A7), U2.9 (A7), U3.9 (A7), U4.9 (A7), U5.9 (A7), U6.9 (A7), U7.9 (A7), U8.9 (A7), U9.9 (A7), U10.9 (A7), U11.9 (A7), U12.9 (A7), U13.9 (A7), U14.9 (A7), U15.9 (A7), U16.9 (A7)
D0: J2.5, U1.2 (DI), U1.14 (D0), U9.2 (DI), U9.14 (D0)
D1: J2.7, U2.2 (DI), U2.14 (D0), U10.2 (DI), U10.14 (D0)
D2: J2.9, U3.2 (DI), U3.14 (D0), U11.2 (DI), U11.14 (D0)
D3: J2.11, U4.2 (DI), U4.14 (D0), U12.2 (DI), U12.14 (D0)
D4: J1.3, U5.2 (DI), U5.14 (D0), U13.2 (DI), U13.14 (D0)
D5: J1.5, U6.2 (DI), U6.14 (D0), U14.2 (DI), U14.14 (D0)
D6: J1.7, U7.2 (DI), U7.14 (D0), U15.2 (DI), U15.14 (D0)
D7: J1.9, U8.2 (DI), U8.14 (D0), U16.2 (DI), U16.14 (D0)
GND: C1.2, C2.2, C3.2, C4.2, C5.2, C6.2, J1.16, J2.1, J2.16, U1.16 (Uss), U2.16 (Uss), U3.16 (Uss), U4.16 (Uss), U5.16 (Uss), U6.16 (Uss), U7.16 (Uss), U8.16 (Uss), U9.16 (Uss), U10.16 (Uss), U11.16 (Uss), U12.16 (Uss), U13.16 (Uss), U14.16 (Uss), U15.16 (Uss), U16.16 (Uss)
/CAS0: J2.4, U1.15 (~CAS), U2.15 (~CAS), U3.15 (~CAS), U4.15 (~CAS), U5.15 (~CAS), U6.15 (~CAS), U7.15 (~CAS), U8.15 (~CAS)
/CAS1: J1.2, TP1.1, TP2.1, TP3.1, TP4.1, TP5.1, TP6.1, TP7.1, TP8.1
/RAS: J2.2, U1.4 (~RAS), U2.4 (~RAS), U3.4 (~RAS), U4.4 (~RAS), U5.4 (~RAS), U6.4 (~RAS), U7.4 (~RAS), U8.4 (~RAS), U9.4 (~RAS), U10.4 (~RAS), U11.4 (~RAS), U12.4 (~RAS), U13.4 (~RAS), U14.4 (~RAS), U15.4 (~RAS), U16.4 (~RAS)
/WE: J2.3, U1.3 (~WE), U2.3 (~WE), U3.3 (~WE), U4.3 (~WE), U5.3 (~WE), U6.3 (~WE), U7.3 (~WE), U8.3 (~WE), U9.3 (~WE), U10.3 (~WE), U11.3 (~WE), U12.3 (~WE), U13.3 (~WE), U14.3 (~WE), U15.3 (~WE), U16.3 (~WE)

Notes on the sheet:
Pin 34
Pin 18
Pinabstand: 2,5 mm Reihenabstand: 37,5 mm

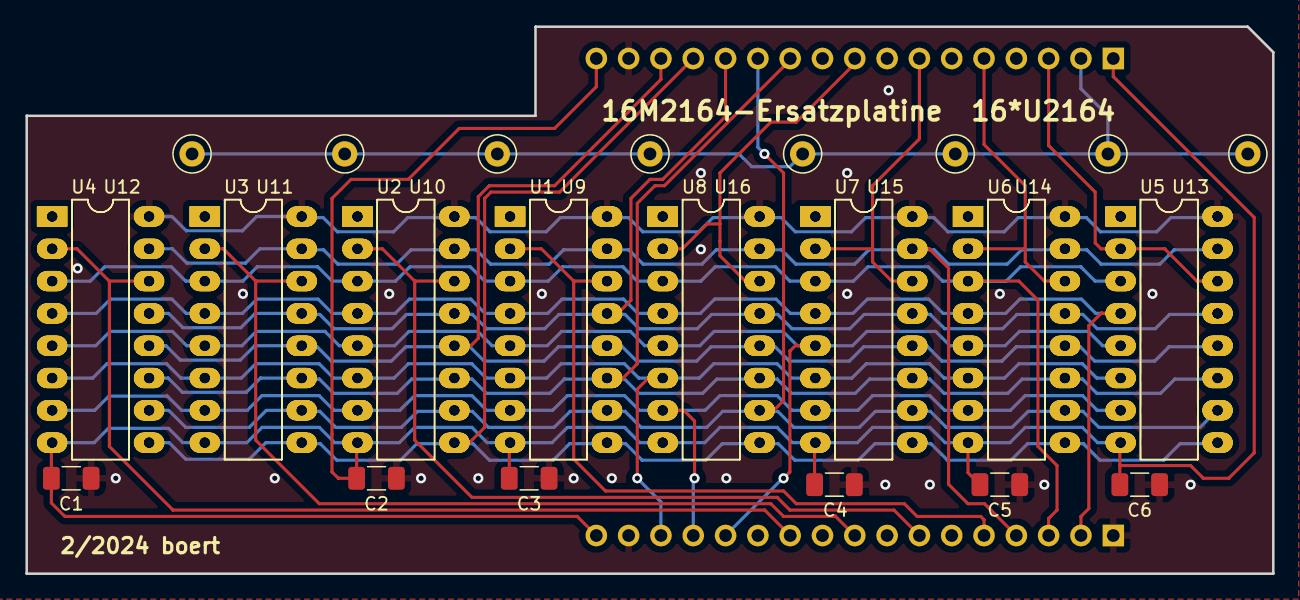
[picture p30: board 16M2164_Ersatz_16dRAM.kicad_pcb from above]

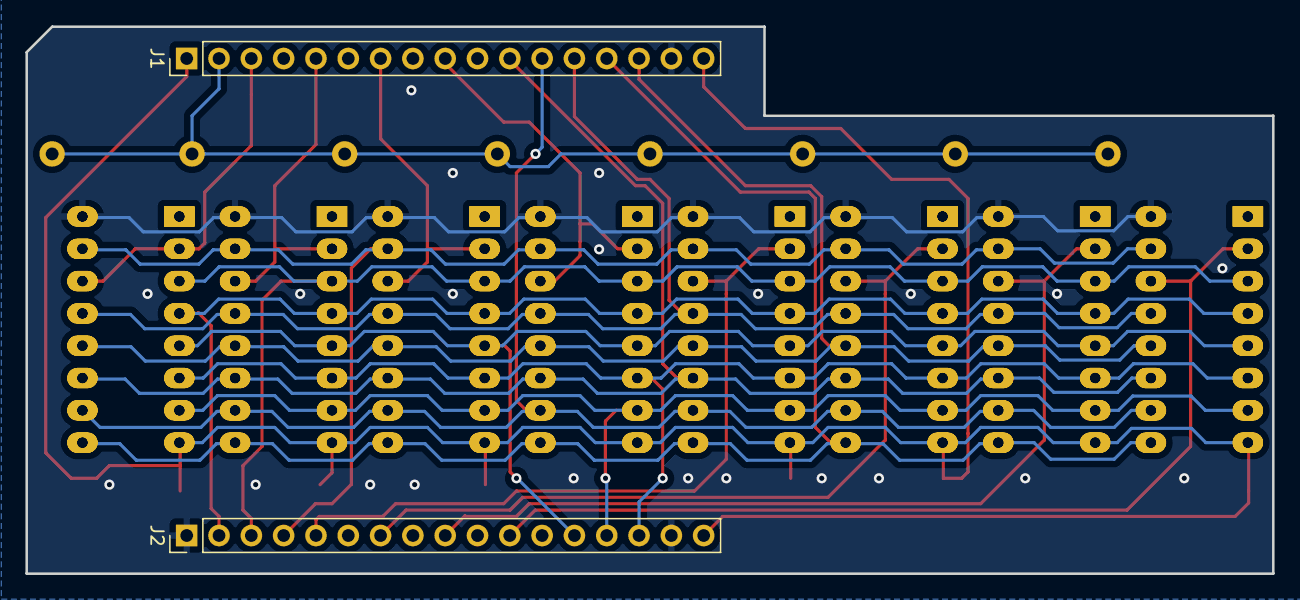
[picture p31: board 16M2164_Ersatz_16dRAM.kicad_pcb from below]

Board: 2 copper layers, 98.0 x 43.0 mm, 32 parts (2 on the bottom side), 22 nets.

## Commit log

2024-02-29 add: Variante D
    [16M2164_Ersatz_16dRAM-B_Cu.gbr, 16M2164_Ersatz_16dRAM-B_Mask.gbr, 16M2164_Ersatz_16dRAM-B_Paste.gbr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]
2024-02-29 add: Variante S
    [16M2164_Ersatz_SRAM-B_Cu.gbr, 16M2164_Ersatz_SRAM-B_Mask.gbr, 16M2164_Ersatz_SRAM-B_Paste.gbr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]
2024-03-25 add: Modulblende
    [M036_Frontblende.kicad_pcb]
